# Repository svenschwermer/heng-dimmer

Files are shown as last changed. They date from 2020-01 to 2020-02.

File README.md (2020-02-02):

# Heng Balance Lamp Dimmer
This is a simple dimmer module that is designed for the Heng Balance Lamp that
materialized on [Kickstarter][1] a while back and is available through various
distributors.

## Circuit
The circuit was designed with components that I had at hand at the time.
Luckily, the lamp is powered via a USB power supply, so I could just pulse width
modulate the supply to the lamp in line. The switching transistor is a
[BUZ11][2] N-channel MOSFET. It's driven directly by one of the output compare
pins of the [ATtiny13A][3].

The user adjusts the PWM duty cycle (i.e. brightness) via a rotary encoder that
includes a push button switch. The wires are soldered directly to the underside
of the circuit board. Holes allow to install cable ties as strain relief.

The PCB is shared on [OSH Park][4].

## Firmware
The program configures the timer to run in fast PWM mode with a prescaler of 8.
Since I didn't change the clocking fuses, the microcontroller runs at 1.2MHz.
With the prescaler and the 8 bit resolution, the PWM frequency ends up being
586Hz which is sufficient to not see flicker.

7 distinct brightness levels can be selected by turning the rotary encoder.
Pushing it brings the lamp to full brightness if it wasn't already. It switches
the lamp completely off otherwise. This allows toggling between off and fully on
by pushing the button.

The encoder phase and button inputs are sampled every time the timer overflows,
i.e. with the same frequency as the PWM frequency. The button is debounced by
requiring it to be pushed for > 107ms.

*Note:* When the JTAGICE3 is attached to the board, the push button
functionality doesn't work reliably since the programmer seems to include a
pull-up resistor on the SCK line.

## Housing
The housing allows the populated circuit board to be fastened by the rotary
encoder nut. Unfortunately, the design doesn't allow the PCB to be taken out
once the cables are installed. Neither is it possible to access the programming
header once the cables are installed and the PCB is installed in the housing.

The big radius on the back side allows to fasten the entire unit to the round
base of the lamp using cable ties.

## Pictures
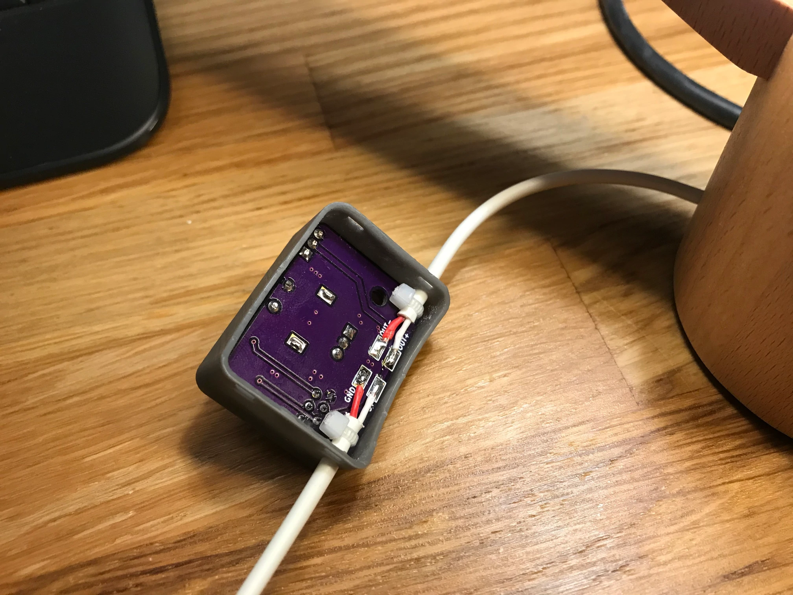
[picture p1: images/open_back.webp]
Backside of assembled module

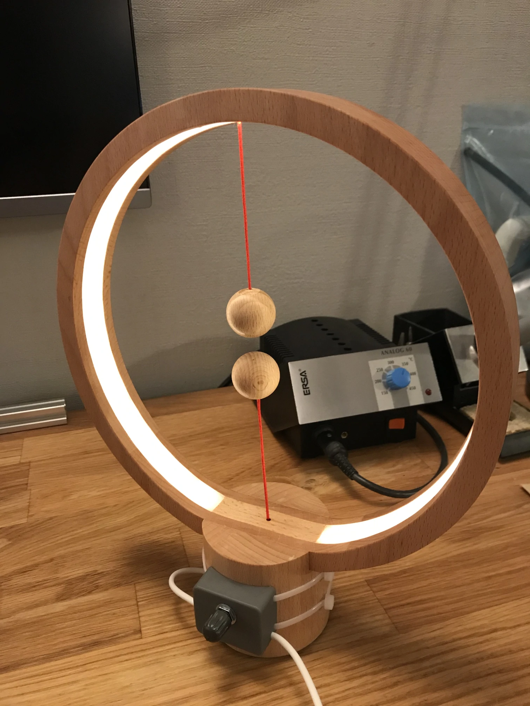
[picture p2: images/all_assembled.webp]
Attached to lamp


[1]:https://www.kickstarter.com/projects/1458079400/heng-balance-lamp-a-unique-lamp-with-switch-in-mid
[2]:https://www.onsemi.com/pub/Collateral/BUZ11-D.PDF
[3]:http://ww1.microchip.com/downloads/en/DeviceDoc/doc8126.pdf
[4]:https://oshpark.com/shared_projects/AtPNl2Sx

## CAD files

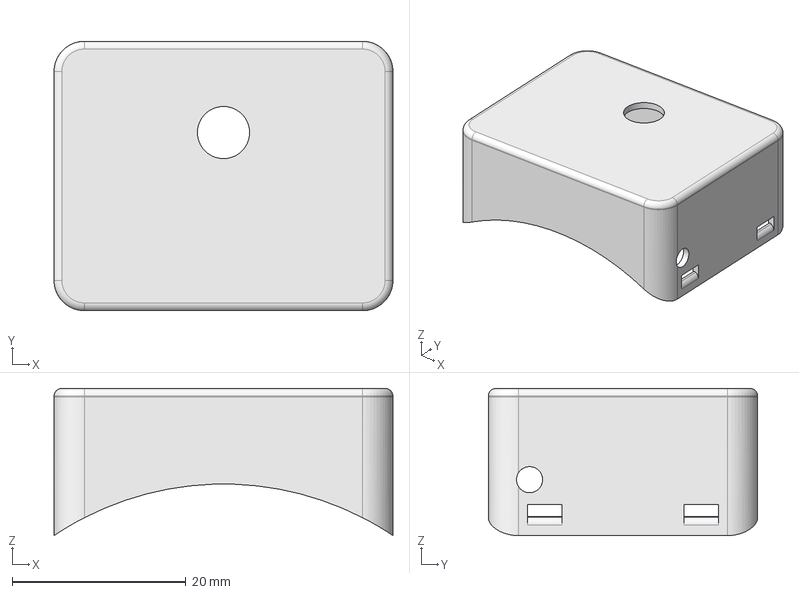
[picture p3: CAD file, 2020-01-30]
housing/heng-dimmer-housing.step
39.0 x 31.0 x 16.9 mm

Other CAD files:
housing/heng-dimmer-housing.FCStd
housing/heng-dimmer-housing.stl

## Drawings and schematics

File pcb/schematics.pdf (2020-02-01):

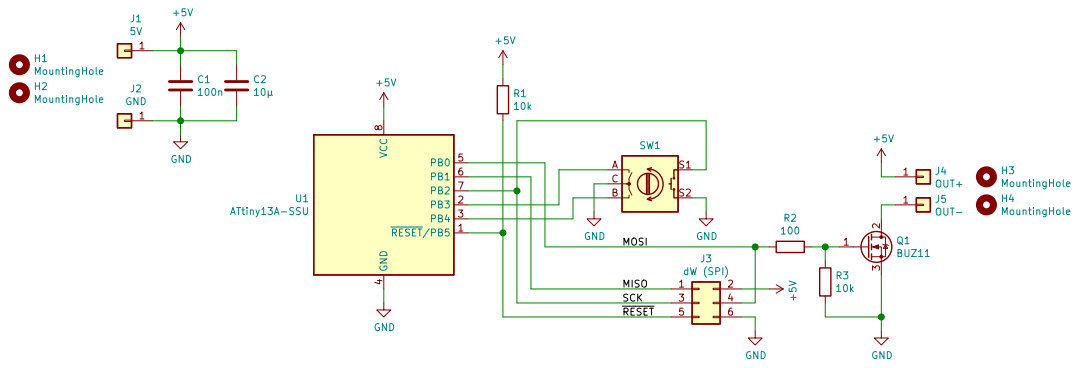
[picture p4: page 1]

File: heng-dimmer.sch Sheet: /
Id: 1/1 Title:

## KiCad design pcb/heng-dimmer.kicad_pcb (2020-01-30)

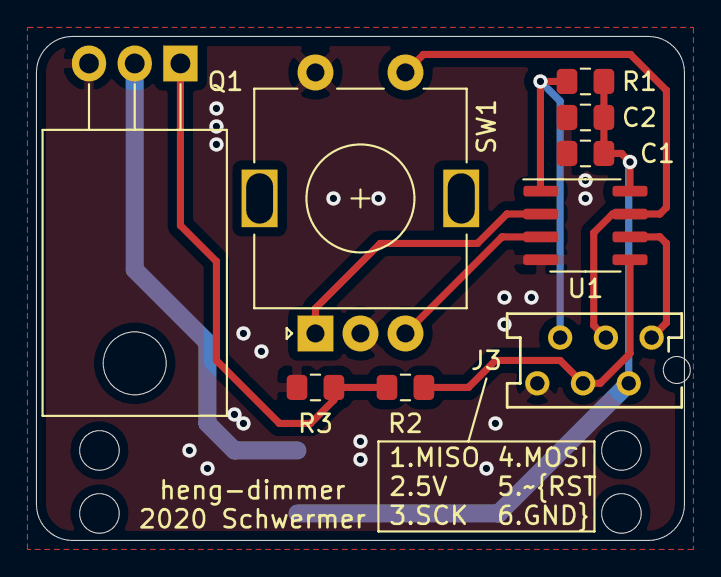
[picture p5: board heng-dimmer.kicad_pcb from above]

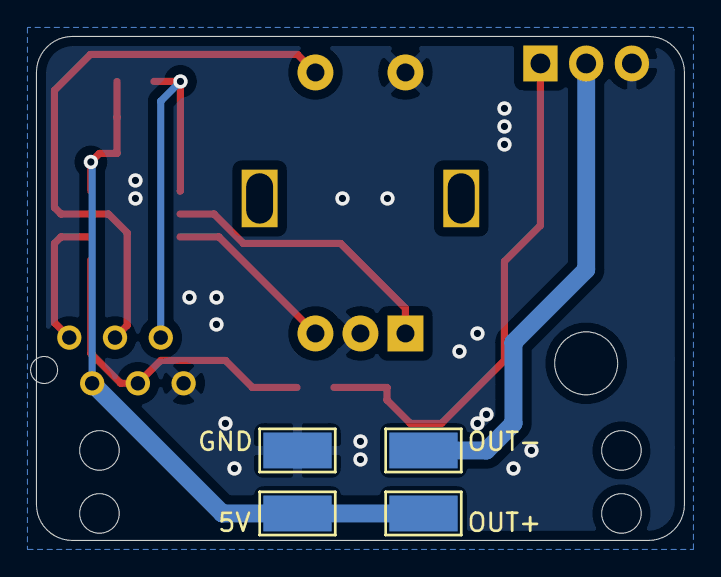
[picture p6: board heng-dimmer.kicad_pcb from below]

Board: 2 copper layers, 36.0 x 28.0 mm, 17 parts (4 on the bottom side), 10 nets.

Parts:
C1: 100n; C_0805_2012Metric_Pad1.15x1.40mm_HandSolder
C2: 10µ; C_0805_2012Metric_Pad1.15x1.40mm_HandSolder
H1, H2, H3, H4: MountingHole; MountingHole_2.2mm_M2
J1: 5V; TestPoint_Keystone_5019_Minature
J2: GND; TestPoint_Keystone_5019_Minature
J3: dW (SPI); TE_MICRO-MATCH_FOB.06P
J4: OUT+; TestPoint_Keystone_5019_Minature
J5: OUT-; TestPoint_Keystone_5019_Minature
Q1: BUZ11; TO-220-3_Horizontal_TabDown
R1, R3: 10k; R_0805_2012Metric_Pad1.15x1.40mm_HandSolder
R2: 100; R_0805_2012Metric_Pad1.15x1.40mm_HandSolder
SW1: Rotary_Encoder_Switch; RotaryEncoder_Alps_EC11E-Switch_Vertical_H20mm
U1: ATtiny13A-SSU; SOIC-8_3.9x4.9mm_P1.27mm

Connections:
+5V: C1.1, C2.1, J1.1, J3.2, J4.1, R1.1, U1.8
/MISO: J3.1, U1.6
/MOSI: J3.4, R2.2, U1.5
/SCK: J3.3, SW1.S1, U1.7
/~RESET: J3.5, R1.2, U1.1
GND: C1.2, C2.2, J2.1, J3.6, Q1.3, R3.2, SW1.C, SW1.S2, U1.4
unnamed: J5.1, Q1.2
unnamed: Q1.1, R2.1, R3.1
unnamed: SW1.A, U1.2
unnamed: SW1.B, U1.3

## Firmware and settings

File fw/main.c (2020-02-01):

#include "encoder.h"
#include <avr/io.h>
#include <avr/interrupt.h>
#include <stdbool.h>

#define MAX_BRIGHTNESS 7

static void enable_fast_pwm(bool enable) {
    // Non-inverted fast PWM on OC0A (PB0)
    TCCR0A = enable ? (_BV(COM0A1) | _BV(WGM01) | _BV(WGM00)) : 0x00;
}

static int8_t set_brightness(int8_t v) {
    if (v <= 0) {
        enable_fast_pwm(false);
        return 0;        
    }

    enable_fast_pwm(true);
    if (v >= MAX_BRIGHTNESS) {
        OCR0A = 0xff;
        return MAX_BRIGHTNESS;
    }
    OCR0A = 1 << (v+1);
    return v;
}

int main() {
    // PB0 as output
    DDRB |= _BV(0);
    // prescaler = 8
    TCCR0B = _BV(CS01);

    encoder_init();
    sei();

    int8_t brightness = 0;
    while(1) {
        if (encoder_pushed()) {
            if (brightness == MAX_BRIGHTNESS)
                brightness = 0;
            else
                brightness = MAX_BRIGHTNESS;
        } else {
            brightness += encoder_read();
        }

        brightness = set_brightness(brightness);
    }
    return 0;
}

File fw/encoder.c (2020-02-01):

/*
    This code is inspired by Peter Dannegger's code:
    https://www.mikrocontroller.net/articles/Drehgeber#Solide_L.C3.B6sung:_Beispielcode_in_C
*/

#include <avr/io.h>
#include <avr/interrupt.h>
#include "encoder.h"

static volatile int8_t enc_delta;
static int8_t last;
static struct
{
    volatile uint8_t press; // pending press
    uint8_t state;          // debounced state
    uint8_t cnt;
} button;

static inline bool phase_a(void)
{
    return !!(PINB & _BV(PIN3));
}

static inline bool phase_b(void)
{
    return !!(PINB & _BV(PIN4));
}

static inline bool button_active(void)
{
    return !(PINB & _BV(PIN2));
}

void encoder_init(void)
{
    enc_delta = 0;
    last = 0;

    DDRB &= ~(_BV(DDB2) | _BV(DDB3) | _BV(DDB4));
    PORTB |= (_BV(DDB2) | _BV(DDB3) | _BV(DDB4));

    if (phase_a())
        last = 3;
    if (phase_b())
        last ^= 1; // convert gray to binary

    // Enable overflow interrupt
    TIMSK0 |= _BV(TOIE0);
}

int8_t encoder_read(void)
{
    int8_t val;
    cli();
    val = enc_delta;
    enc_delta = val & ((1 << STEPS_PER_INDENT) - 1);
    sei();
    return val >> STEPS_PER_INDENT;
}

bool encoder_pushed(void)
{
    bool state;
    cli();
    state = button.press;
    button.press = 0;
    sei();
    return state;
}

ISR(TIM0_OVF_vect)
{
    int8_t diff;
    int8_t new = 0;
    if (phase_a())
        new = 3;
    if (phase_b())
        new ^= 1;      // convert gray to binary
    diff = last - new; // difference last - new
    if (diff & 1)
    {                                // bit 0 = value (1)
        last = new;                  // store new as next last
        enc_delta += (diff & 2) - 1; // bit 1 = direction (+/-)
    }

    if (button_active() != !!button.state)
    {
        if (++button.cnt == 0x3f)
        {
            button.state = !button.state;
            if (button.state)
                button.press = 1;
        }
    }
    else
        button.cnt = 0;
}
